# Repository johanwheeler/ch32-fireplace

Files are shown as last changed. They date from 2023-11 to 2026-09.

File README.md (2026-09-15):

# Merry Christmas!

And a happy new year! Here you will find some instructions for the christmas card, as well as some technical details. 

https://github.com/johanwheeler/ch32-fireplace/assets/45564940/a2e65534-c451-412c-9a83-9337bf3cca4e

[Longer demo here](https://photos.app.goo.gl/RaVmtgkoQ25G9iBE6), [Short Hackaday article](https://hackaday.com/2024/01/02/an-animated-led-fireplace-powered-by-the-ch32v003/)

# Instructions

If your card has white plastic in front of the screen, remove the front plate and peel the film, then connect to any USB-C power source. The stockings above the fire are actually touch buttons! Press firmly to interact.

Sound: Toggle sound on or off. 

Next: Go to next animation.

Present: Call for santa. Remember that santa will only deliver presents at night ;)

# Technical details

For fellow nerds.

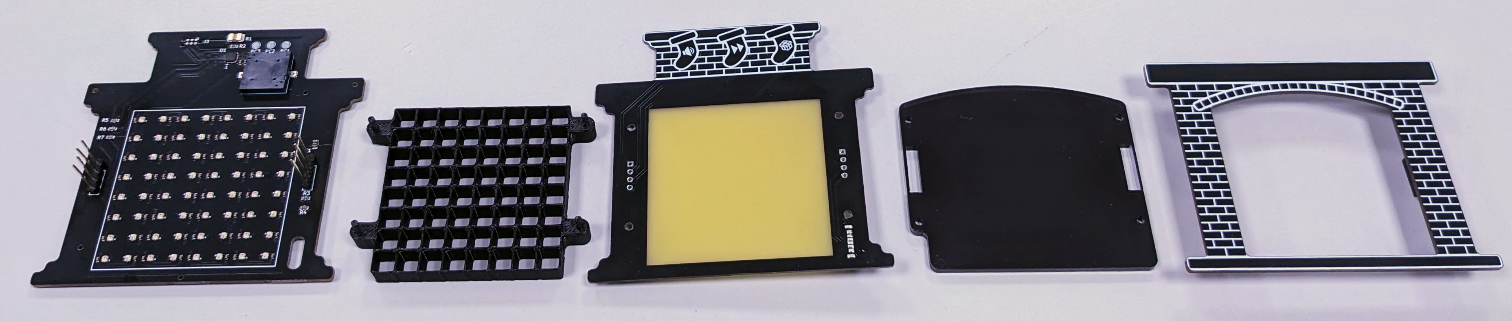
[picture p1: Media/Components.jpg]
Major components laid out


## Mechanical design

The initial shape was made in Fusion360, together with the grid and acrylic piece. The outlines were then imported into Inkscape, where the graphics were designed. To save ourselves a lot of work during the assembly process, we put an effort into minimizing part count as much as possible. We did this by combining multiple functions into one part, for example the middle PCB serves as decoration, diffuser for the LEDs, and also has buttons integrated. This way we managed to get all the looks and functionality with only 5 major mechanical components, saving us a lot of work when we eventually assembled all 50 of these.

## Electrical design

The main electrical components are:

 - CH32V003 RISC-V microcontroller
 - WS2812B (neopixel) LED matrix with 64 pixels
 - Buzzer for music and sound effects
 - Capacitive touch buttons
 - Photoresistor

These are distributed on 3 PCBs for a 3D effect, KiCAD was used to design the PCBs:

 - Back PCB has most of the components including MCU, Buzzer, LEDs, and programming headers.
 - Middle PCB has a USB-C port and capacitive buttons. Exposed FR-4 is used as a diffuser for the LEDs. 
 - Front PCB just looks nice.

## Assembly

The project is assembled in several steps that need to be followed in the correct order.

 - Components on back PCB.
 - Upload code (on back PCB).
 - Attach USB-C jack and grid on middle PCB.
 - Solder middle PCB to back PCB headers.
 - Attach acrylic on middle PCB.
 - Solder female headers on front PCB.
 - Attach front PCB.
 - Plug in and enjoy!

We got all of the back PCB smd components assembled by JLCPCB. We then set up a mini production line over the weekend and made 50 of these to give away to friends and family. The final cost came out to around 6$ per fireplace, manageable even with our student budgets. 

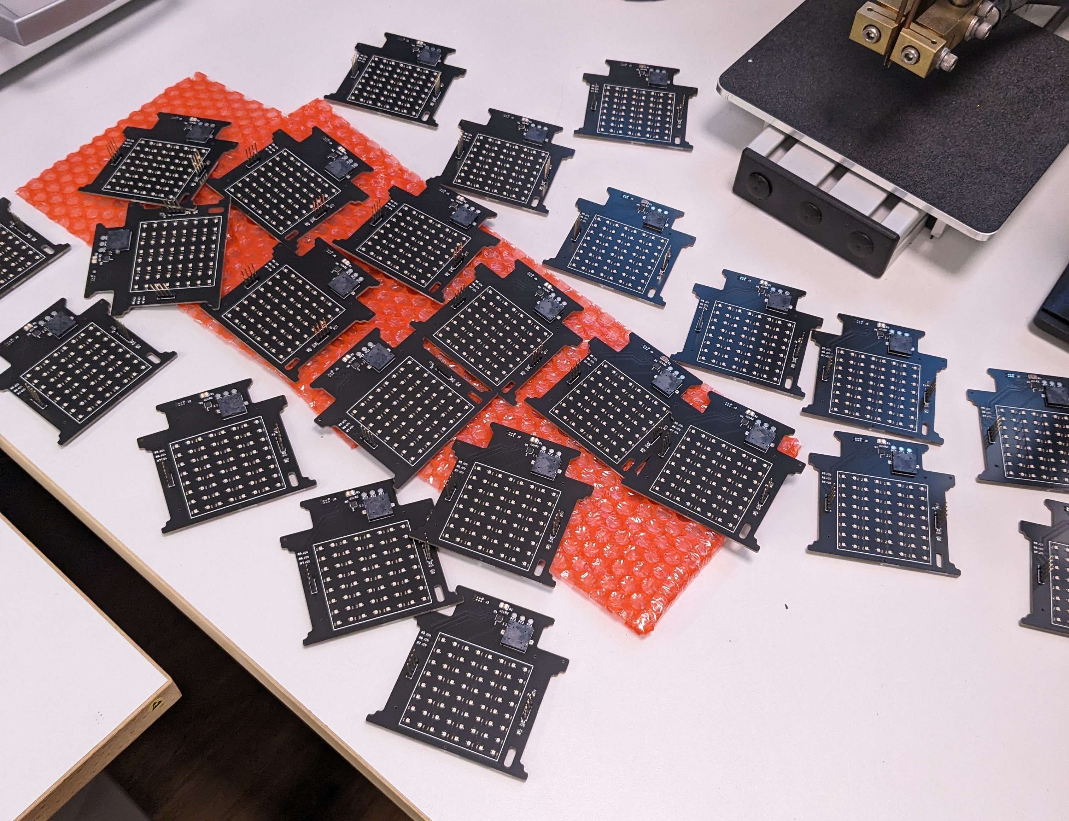
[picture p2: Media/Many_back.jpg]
Headers soldered to back


## Code

All code was written in plain C using the ch32v003fun dev environment and can be compiled using PlatformIO. The main code can be found in [src/main.c](SW/fireplace-PIO/src/main.c), and several peripheral drivers and functions can be found in the [lib](SW/fireplace-PIO/lib/) folder. The fire is procedurally generated, and the christmas tree has some math for the fading lights, otherwise the animations are stored frame by frame on the device. We really managed to squeeze a lot of functionality onto the 10 cent chip, with the code, animations and music filling up more than 90 percent of the 16k flash. 

# Contributions

This was a really fun project to do, and we learned a lot about small-scale production with limited budget and a tight deadline.

The people who made this:

 - Johan Wheeler (@johanwheeler): Electrical design, mechanical design, assembly.
 - Daniel Quach (@BasementCircuits): Project lead, electrical design, programming, animations, soldering.
 - Adam Anderson (@adaand00): Mechanical design, assembly, programming, animations. 

[See past years' cards!](https://github.com/Muoshy/christmas-cards)

Additional thanks to:

@CNLohr and contributors for the great resources in [ch32v003fun](https://github.com/cnlohr/ch32v003fun/tree/master).

CASE (Chalmers Autonomous Sytems and Electronics) for PCB shipping, tools, and workspace.

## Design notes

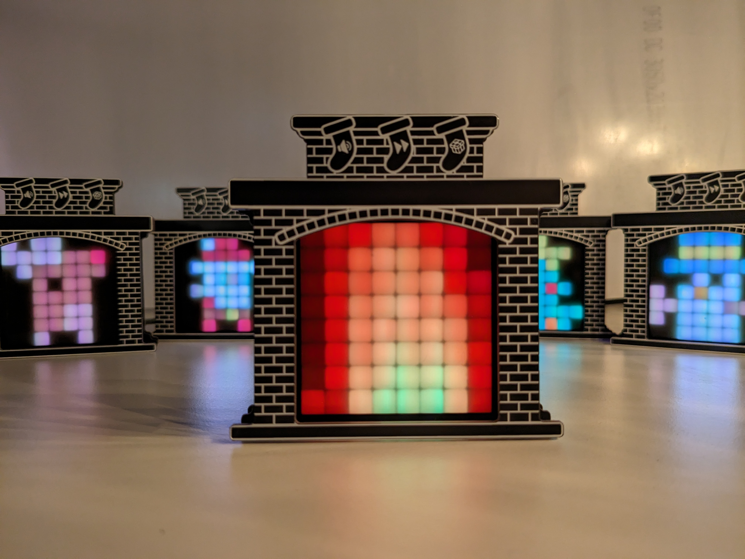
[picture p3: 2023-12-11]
Media/Display.jpg

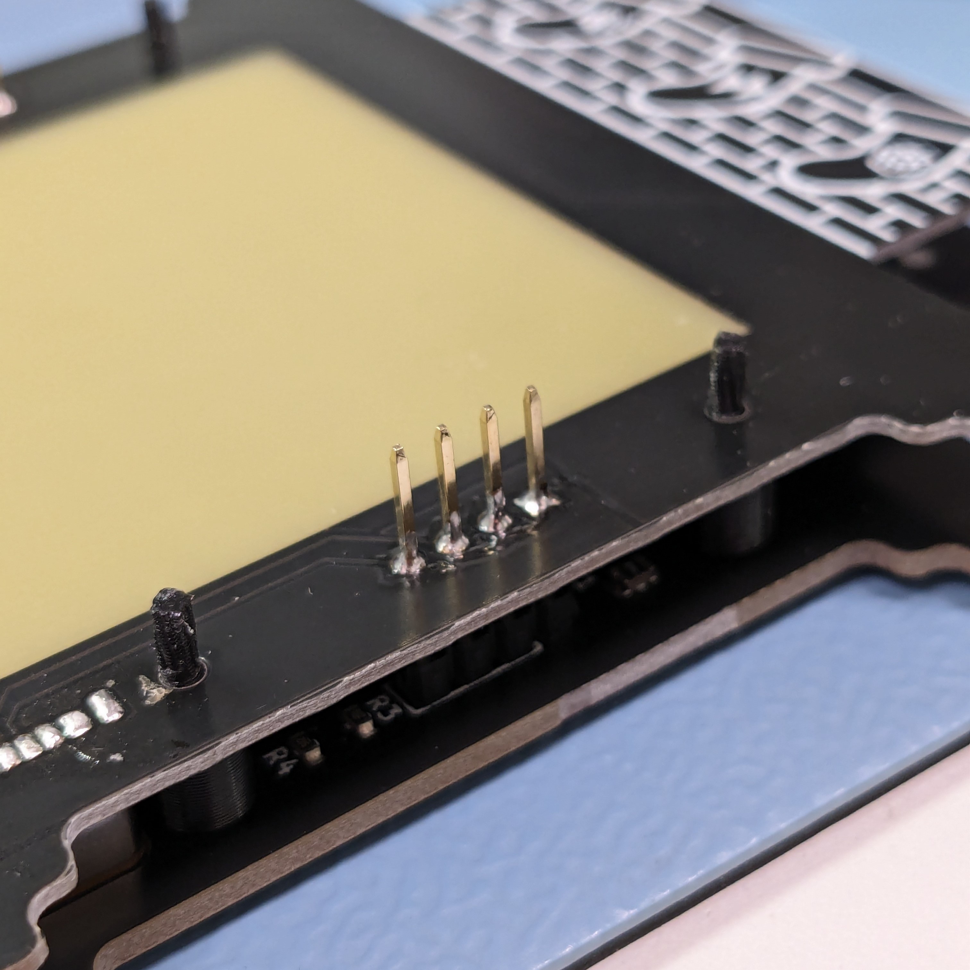
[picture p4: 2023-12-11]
Media/Mid_attached.jpg

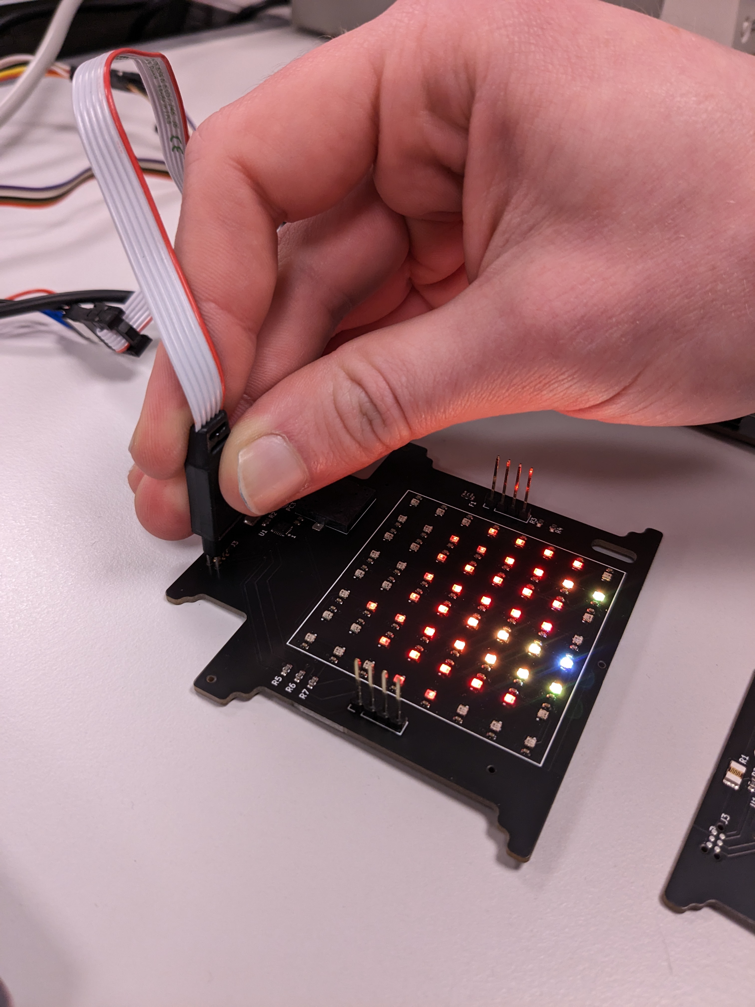
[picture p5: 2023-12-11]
Media/Programming.jpg

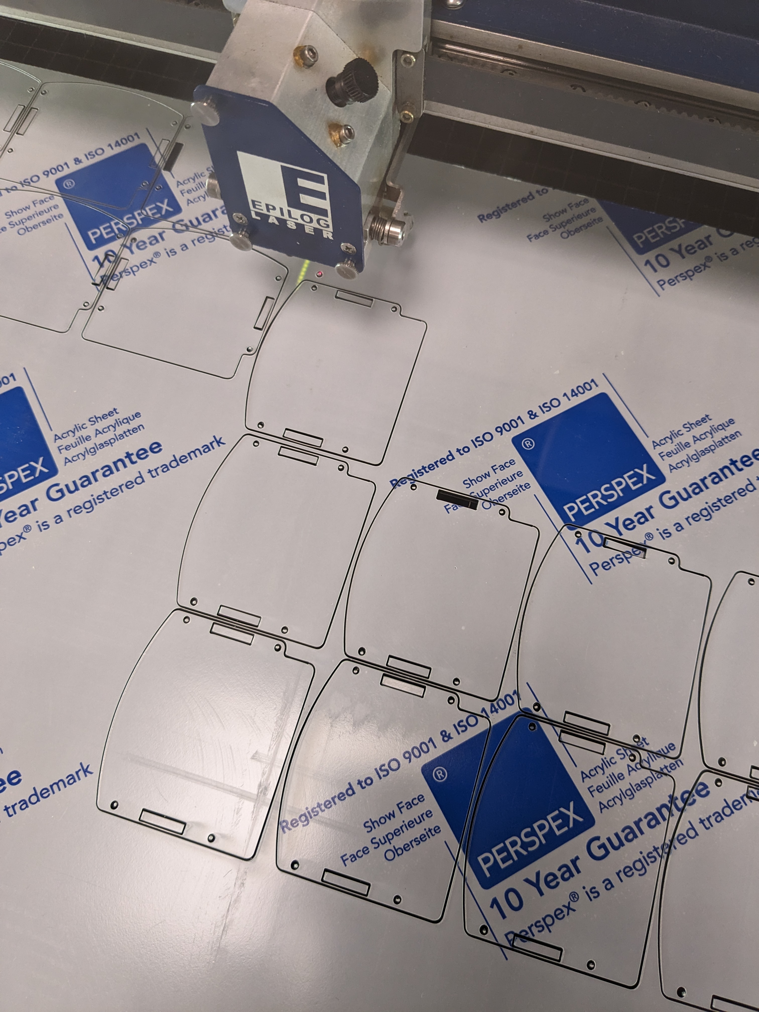
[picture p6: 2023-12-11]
Media/Laser.jpg

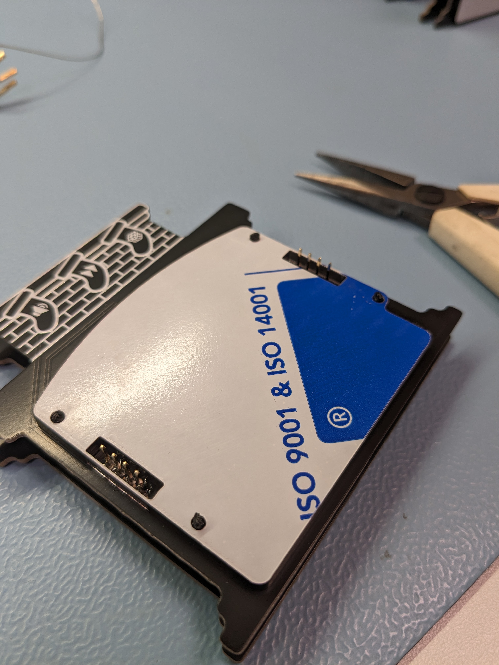
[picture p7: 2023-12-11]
Media/Acryllic.jpg

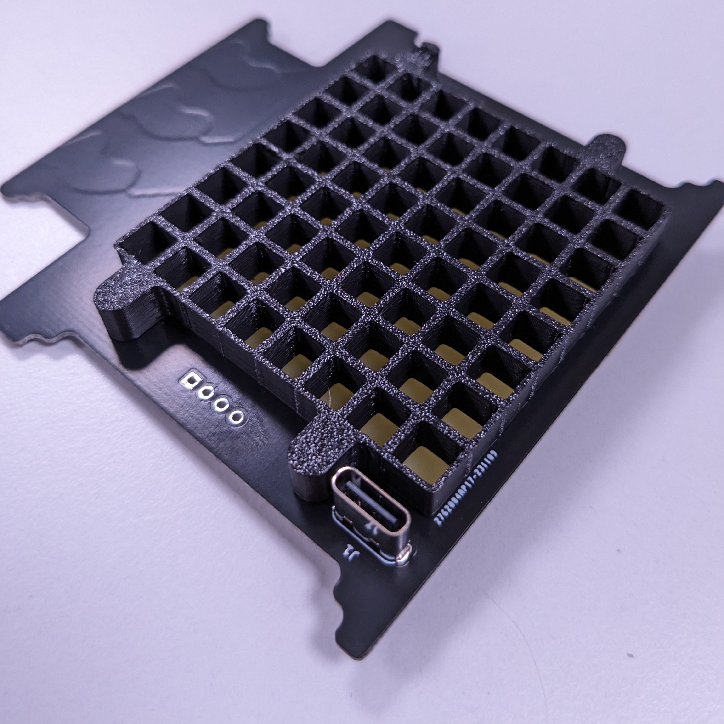
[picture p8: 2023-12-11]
Media/Mid_grid.jpg

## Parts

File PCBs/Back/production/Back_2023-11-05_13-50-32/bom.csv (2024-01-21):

Designator | Footprint | Quantity | Value | LCSC Part #
BZ1 | FUET-1325 | 1 | Buzzer | C391038
C1, C10, C11, C12, C13, C14, C15, C16, C17, C18, C19, C2, C20, C21, C22, C23, C24, C25, C26, C27, C28, C29, C3, C30, C31, C32, C33, C34, C35, C36, C37, C38, C39, C4, C40, C41, C42, C43, C44, C45, C46, C47, C48, C49, C5, C50, C51, C52, C53, C54, C55, C56, C57, C58, C59, C6, C60, C61, C62, C63, C64, C65, C66, C7, C8, C9 | 0402 | 66 | 100n | C1525
D1, D10, D11, D12, D13, D14, D15, D16, D17, D18, D19, D2, D20, D21, D22, D23, D24, D25, D26, D27, D28, D29, D3, D30, D31, D32, D33, D34, D35, D36, D37, D38, D39, D4, D40, D41, D42, D43, D44, D45, D46, D47, D48, D49, D5, D50, D51, D52, D53, D54, D55, D56, D57, D58, D59, D6, D60, D61, D62, D63, D64, D7, D8, D9 | XL-1615_WS2812B | 64 | RGB_1516 | C5349954
F1 | 0805 | 1 | 750mA | C269105
H1, H2, H3 | ToolingHole | 3 | Tooling
J1 | PinHeader_1x04_P2.54mm_Vertical | 1 | PWR_CONN
J4 | PinHeader_1x04_P2.54mm_Vertical | 1 | CAP_CONN
R1 | GT36528 | 1 | Photoresistor | C2904881
R2 | 0603 | 1 | 10k | C31850
R3, R4 | 0603 | 2 | 5.1k | C23186
R5, R6, R7 | 0603 | 3 | 560k | C23203
TP1 | TestPoint_Pad_D2.0mm | 1 | PC3
TP2 | TestPoint_Pad_D2.0mm | 1 | PC2
TP3 | TestPoint_Pad_D2.0mm | 1 | PC1
U1 | QFN-20-1EP_3x3mm_P0.4mm_EP1.65x1.65mm | 1 | CH32V003F4U6 | C5299908

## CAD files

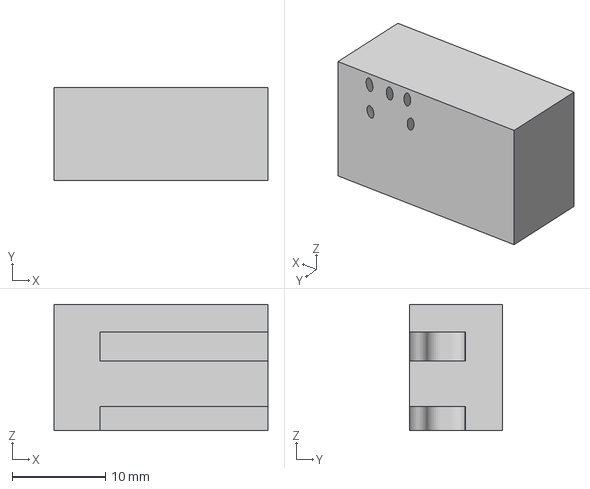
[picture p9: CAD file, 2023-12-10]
CAD/3D/pogo_block_0.1.3mf
23.0 x 10.0 x 13.6 mm

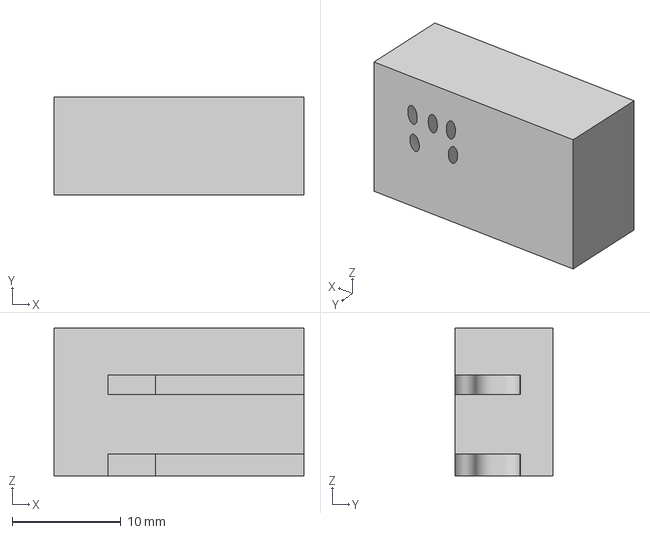
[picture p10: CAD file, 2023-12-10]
CAD/3D/pogo_block_v2/pogo_block_v2_mean_offset.3mf
23.0 x 9.00 x 13.6 mm

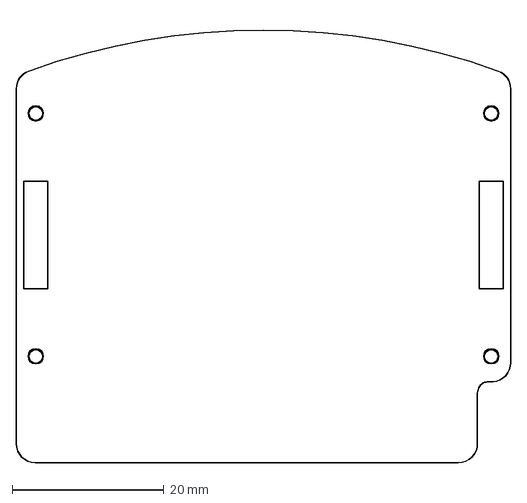
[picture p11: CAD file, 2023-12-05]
CAD/DXF/acrylic_v2.dxf
65.1 x 58.8 mm

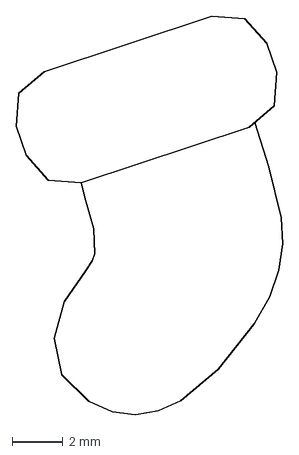
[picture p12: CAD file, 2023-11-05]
Graphics/sock_1mm.dxf
10.5 x 15.7 mm

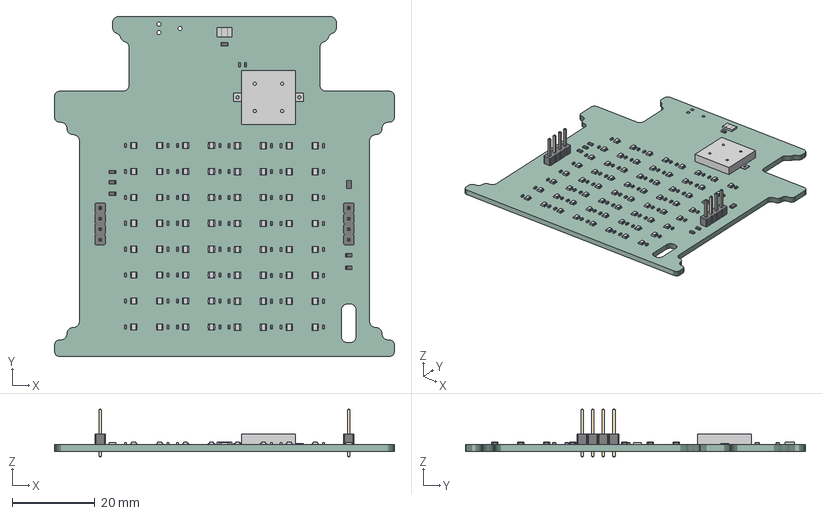
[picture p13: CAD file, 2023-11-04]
PCBs/Back/Back.step
82.0 x 82.0 x 11.5 mm
_autosave-Back PCB

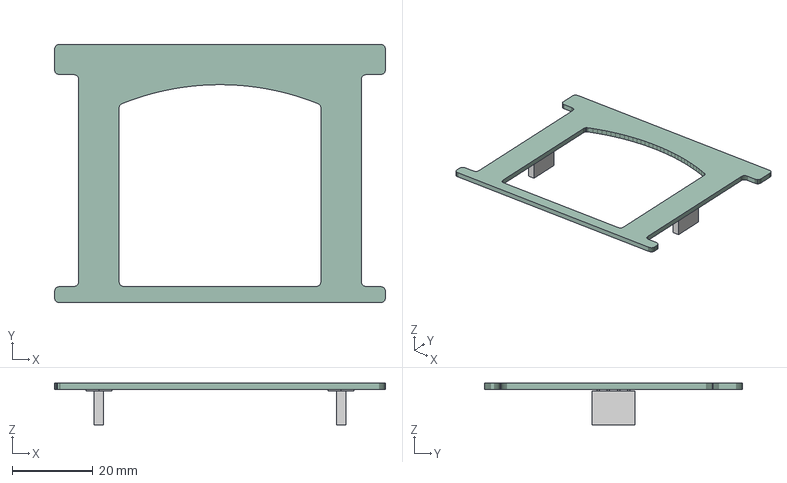
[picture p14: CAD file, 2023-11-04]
PCBs/Front/Front.step
82.0 x 64.0 x 10.4 mm
_autosave-Front PCB

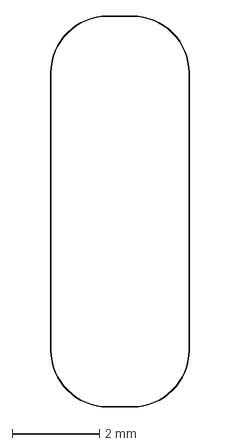
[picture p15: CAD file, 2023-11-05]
PCBs/Middle/usb-c-outline.dxf
3.16 x 8.94 mm

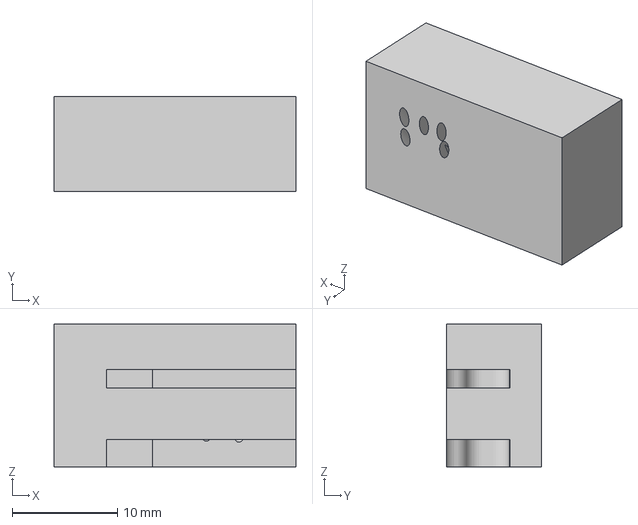
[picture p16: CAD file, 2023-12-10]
CAD/3D/pogo_block_v2/pogo_block_v2_back_front_offset.3mf
23.0 x 9.00 x 13.6 mm

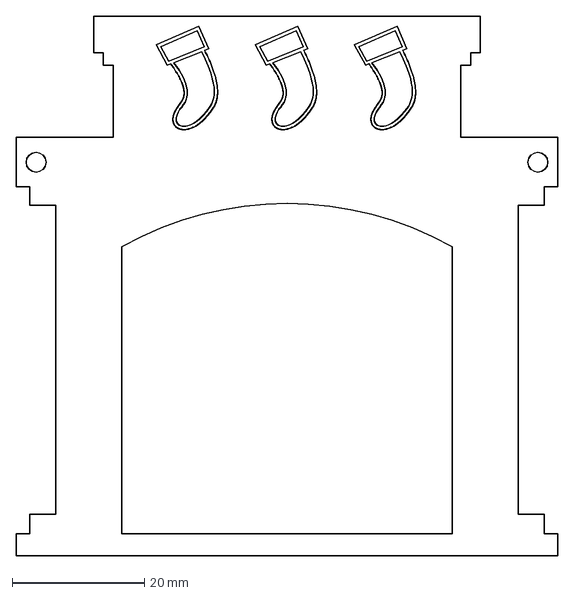
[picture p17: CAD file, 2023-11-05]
CAD/DXF/middle.dxf
82.0 x 81.7 mm

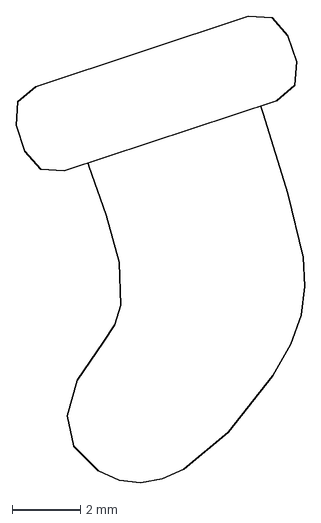
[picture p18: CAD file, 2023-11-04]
Graphics/sock.dxf
8.48 x 13.7 mm

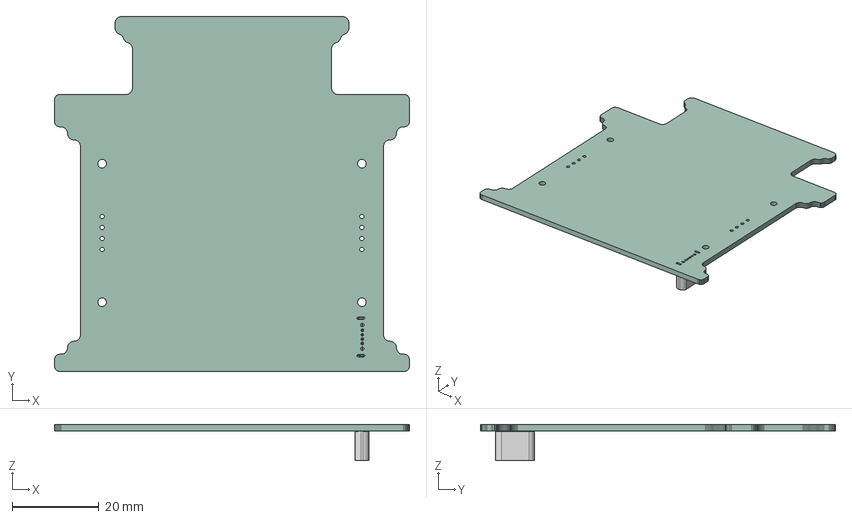
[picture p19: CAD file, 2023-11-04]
PCBs/Middle/Middle.step
82.0 x 82.0 x 8.43 mm
Middle PCB

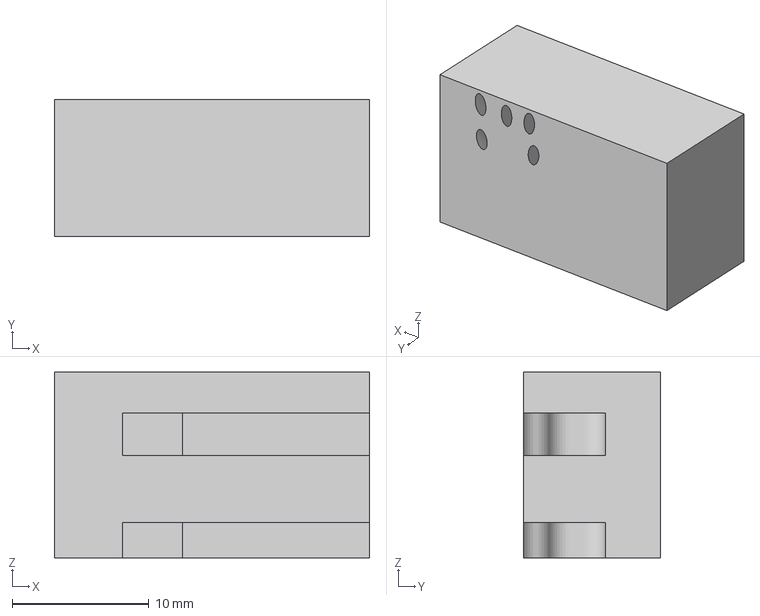
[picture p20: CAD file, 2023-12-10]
CAD/3D/pogo_block_0.2.3mf
23.0 x 10.0 x 13.6 mm

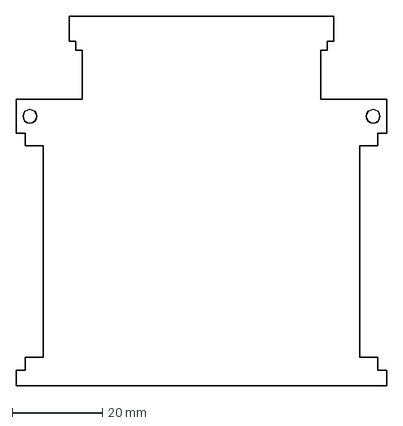
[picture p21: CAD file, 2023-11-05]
CAD/DXF/back.dxf
82.0 x 81.7 mm

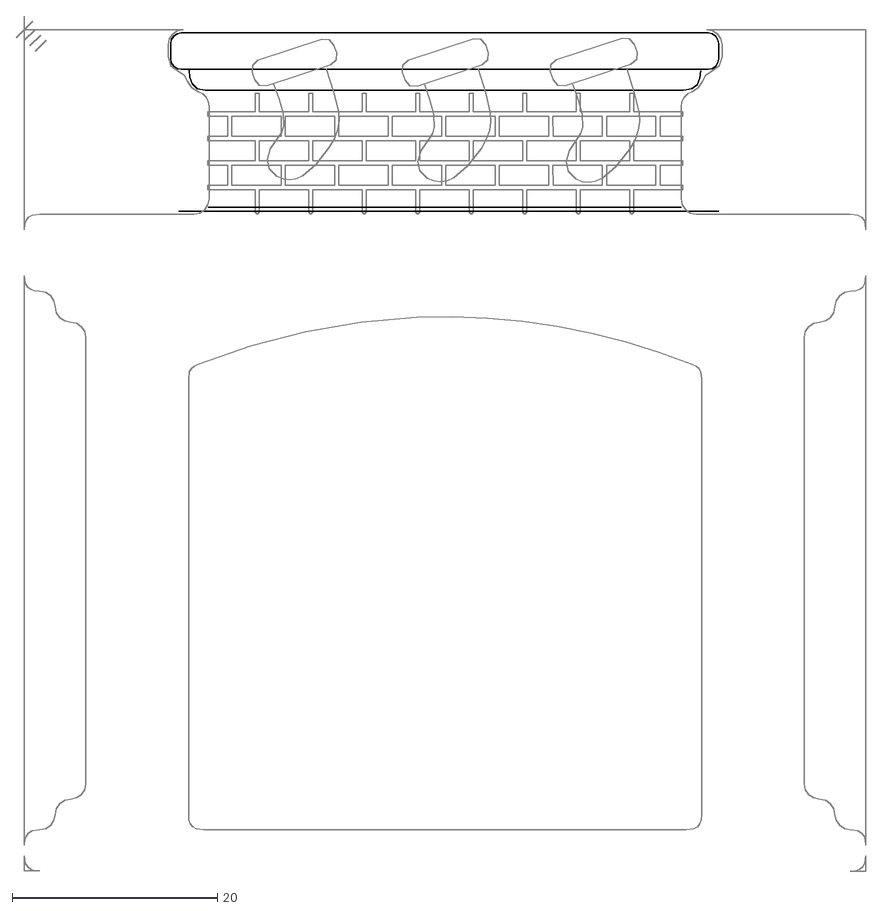
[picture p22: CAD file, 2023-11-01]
Graphics/Middle.dxf
82.8 x 83.3

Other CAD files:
CAD/3D/pogo_block_0.3mf
CAD/3D/pogo_block_printmf.3mf
CAD/DXF/usb-c-cutout.dxf
Graphics/Back.dxf
CAD/3D/1.5mm led grid.stl
CAD/3D/Grid_v3.0.3mf
CAD/3D/Grid_v3.0_diffuse_print.3mf
CAD/3D/Grid_v3.0_print.3mf
CAD/3D/Grid_v3.1.3mf
CAD/3D/Grid_v3.1_6.5mm_high.3mf
CAD/3D/Grid_v3.1_print3mf.3mf
CAD/3D/blablab.3mf
CAD/3D/buzzer_C391038.step
CAD/3D/female_pin_header.step
CAD/3D/footprint_test v2.step
CAD/3D/led_C191KRKT.step
CAD/3D/photo_GT36528.step
CAD/3D/pinHeaderJig.3mf
CAD/3D/pinHeaderJig_v2.3mf
CAD/3D/pinHeaderJig_v3.3mf
CAD/3D/pinHeaderJig_v4.3mf
CAD/3D/pinHeaderJig_v4_print.3mf
CAD/3D/pogo_block_0.3.3mf
CAD/3D/pogo_block_0.4.3mf
CAD/3D/pogo_block_print_V2.3mf
CAD/DXF/front.dxf
Graphics/Front.dxf

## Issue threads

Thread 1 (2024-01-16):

Recreation

AaHug, 2024-01-16:
I'm pretty amature at this, and have a much more knowledge friend helping me.  He was trying to upload the PCB files to jlcpcb.  It wasn't generating a needed parts list.  I've been told we are looking for a Bill of Materials and a Placement file.  Any help would be appreciated.

Muoshy, 2024-01-21:
Good catch! Seems like the BOM and placements files (.csv) were excluded by our gitignore. It should be fixed now. You can find them in PCBs/Back/Production. Otherwise, you can generate the BOM and placement files with the fabrication toolkit plugin in KiCad. The KiCad files should contain the JLCPCB part numbers.

Let me know if you need additional help or if I can close the issue.

AaHug, 2024-01-21:
It's fixed now.  Thank you so much for your help.

Aaron Hugenberg

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

Closed 2024-01-22.

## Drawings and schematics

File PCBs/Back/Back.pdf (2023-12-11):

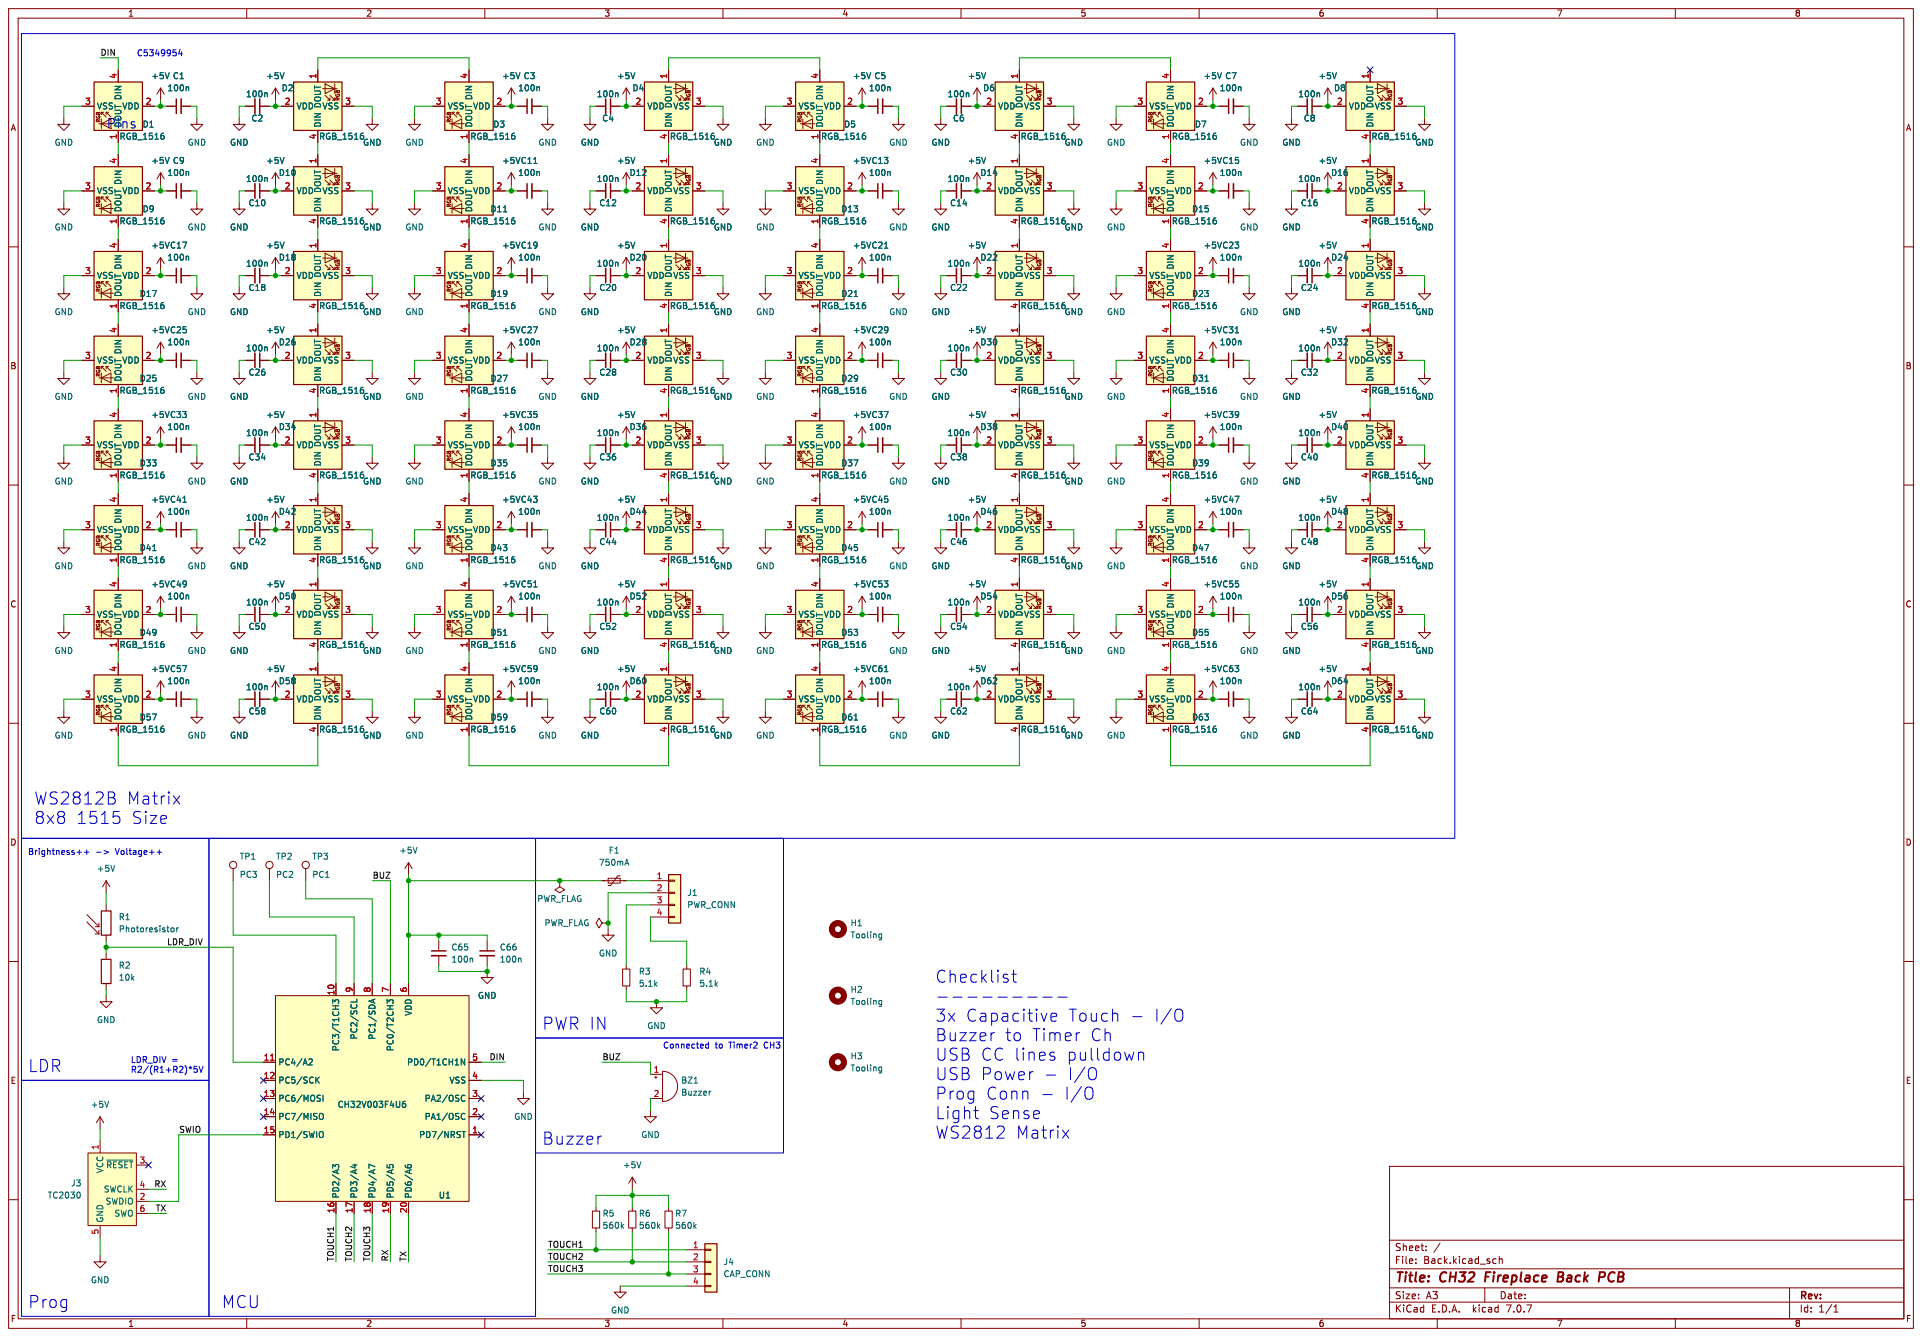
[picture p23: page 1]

4 D22 RGB_1516 GND GND RGB DOUT

4 D11 RGB_1516 GND GND GND GND GND GND GND

100n GND GND GND GND

4 D46 RGB_1516 GND GND GND GND GND GND
100n +5V GND

4 GND GND GND GND GND GND GND GND

4 D60 RGB_1516 GND GND GND GND RGB DOUT

4 D32 RGB_1516 GND GND RGB DOUT

4 D62 RGB_1516 GND GND GND GND GND

4 U1 CH32V003F4U6 PD7/NRST 1 PC3/T1CH3 10 PC4/A2 11 PC5/SCK 12 PC6/MOSI 13 PC7/MISO 14 PD1/SWIO 15 PD2/A3 16 PD3/A4 17 PD4/A7 18 PD5/A5 19 PA1/OSC 2 PD6/A6 20 PA2/OSC 3 VSS 4 PD0/T1CH1N 5 VDD

Connected to Timer2 CH3 PWR IN

Buzzer to Timer Ch
USB CC lines pulldown
USB Power - I/O
Prog Conn - I/O
Light Sense
WS2812 Matrix

1 SWDIO 2 ~{RESET}3 SWCLK 4 GND

Id: 1/1 Title: CH32 Fireplace Back PCB

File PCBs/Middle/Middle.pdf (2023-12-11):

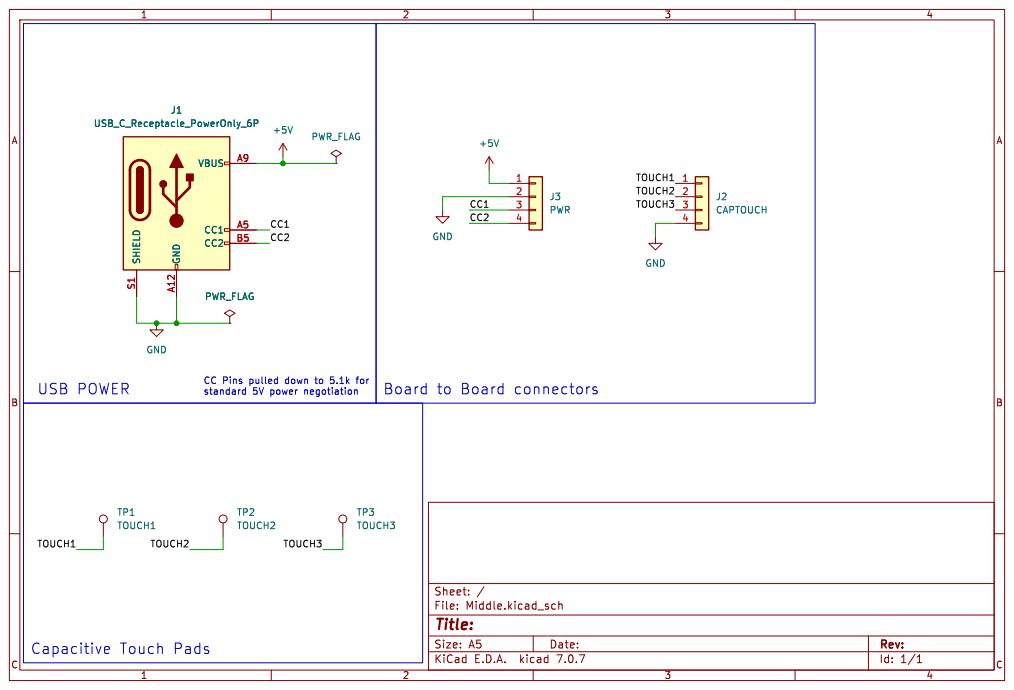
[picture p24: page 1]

J1 USB_C_Receptacle_PowerOnly_6P | +5V

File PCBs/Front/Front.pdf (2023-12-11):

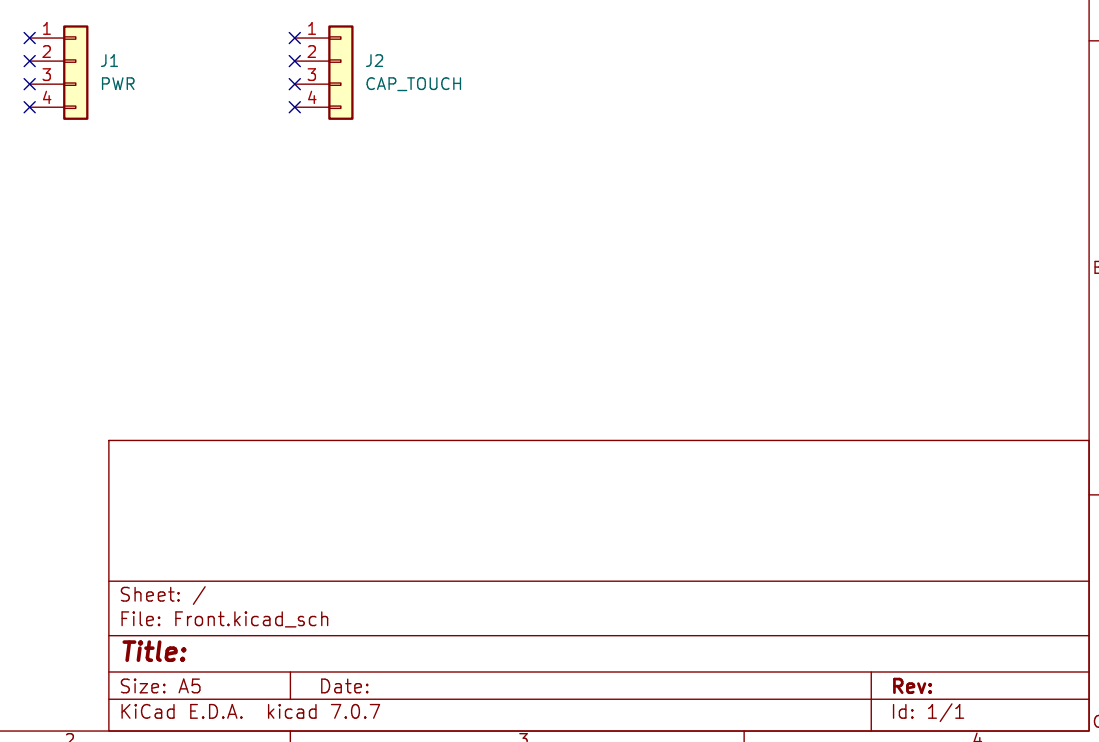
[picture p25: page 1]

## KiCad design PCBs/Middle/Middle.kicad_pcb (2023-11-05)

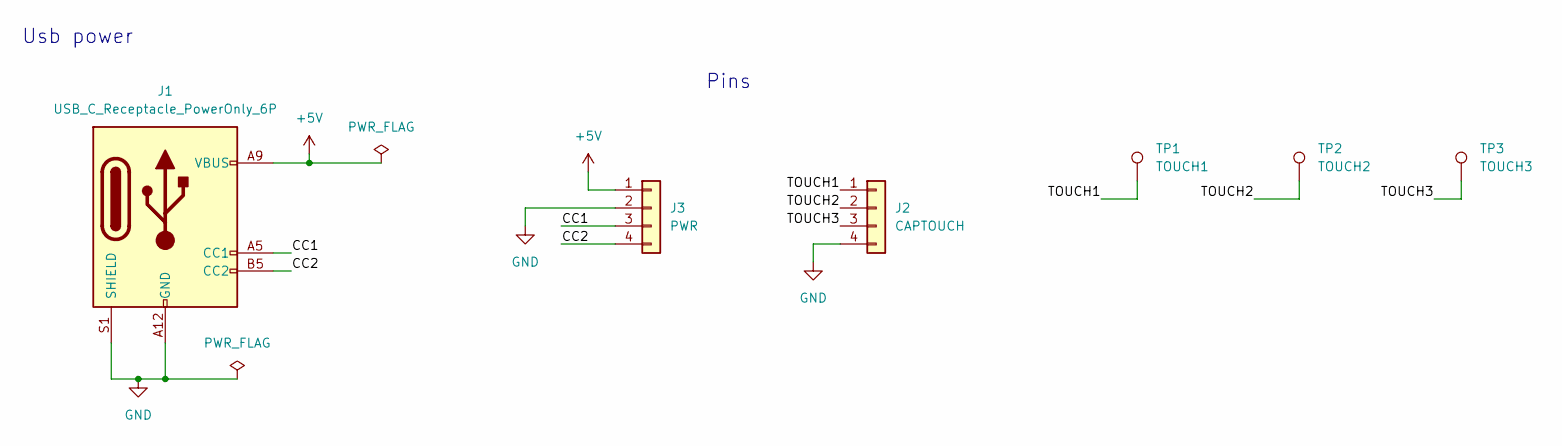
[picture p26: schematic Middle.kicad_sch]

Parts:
J1: USB_C_Receptacle_PowerOnly_6P; TYPE-C-31-D-08
J2: CAPTOUCH; PinHeader_1x04_P2.54mm_Vertical
J3: PWR; PinHeader_1x04_P2.54mm_Vertical
TP1: TOUCH1; cap_sock
TP2: TOUCH2; cap_sock
TP3: TOUCH3; cap_sock

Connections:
+5V: J1.A9 (VBUS), J1.B9 (VBUS), J3.1
/CC1: J1.A5 (CC1), J3.3
/CC2: J1.B5 (CC2), J3.4
/TOUCH1: J2.1, TP1.1
/TOUCH2: J2.2, TP2.1
/TOUCH3: J2.3, TP3.1
GND: J1.A12 (GND), J1.B12 (GND), J1.S1 (SHIELD), J2.4, J3.2

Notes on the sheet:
Usb power
Pins

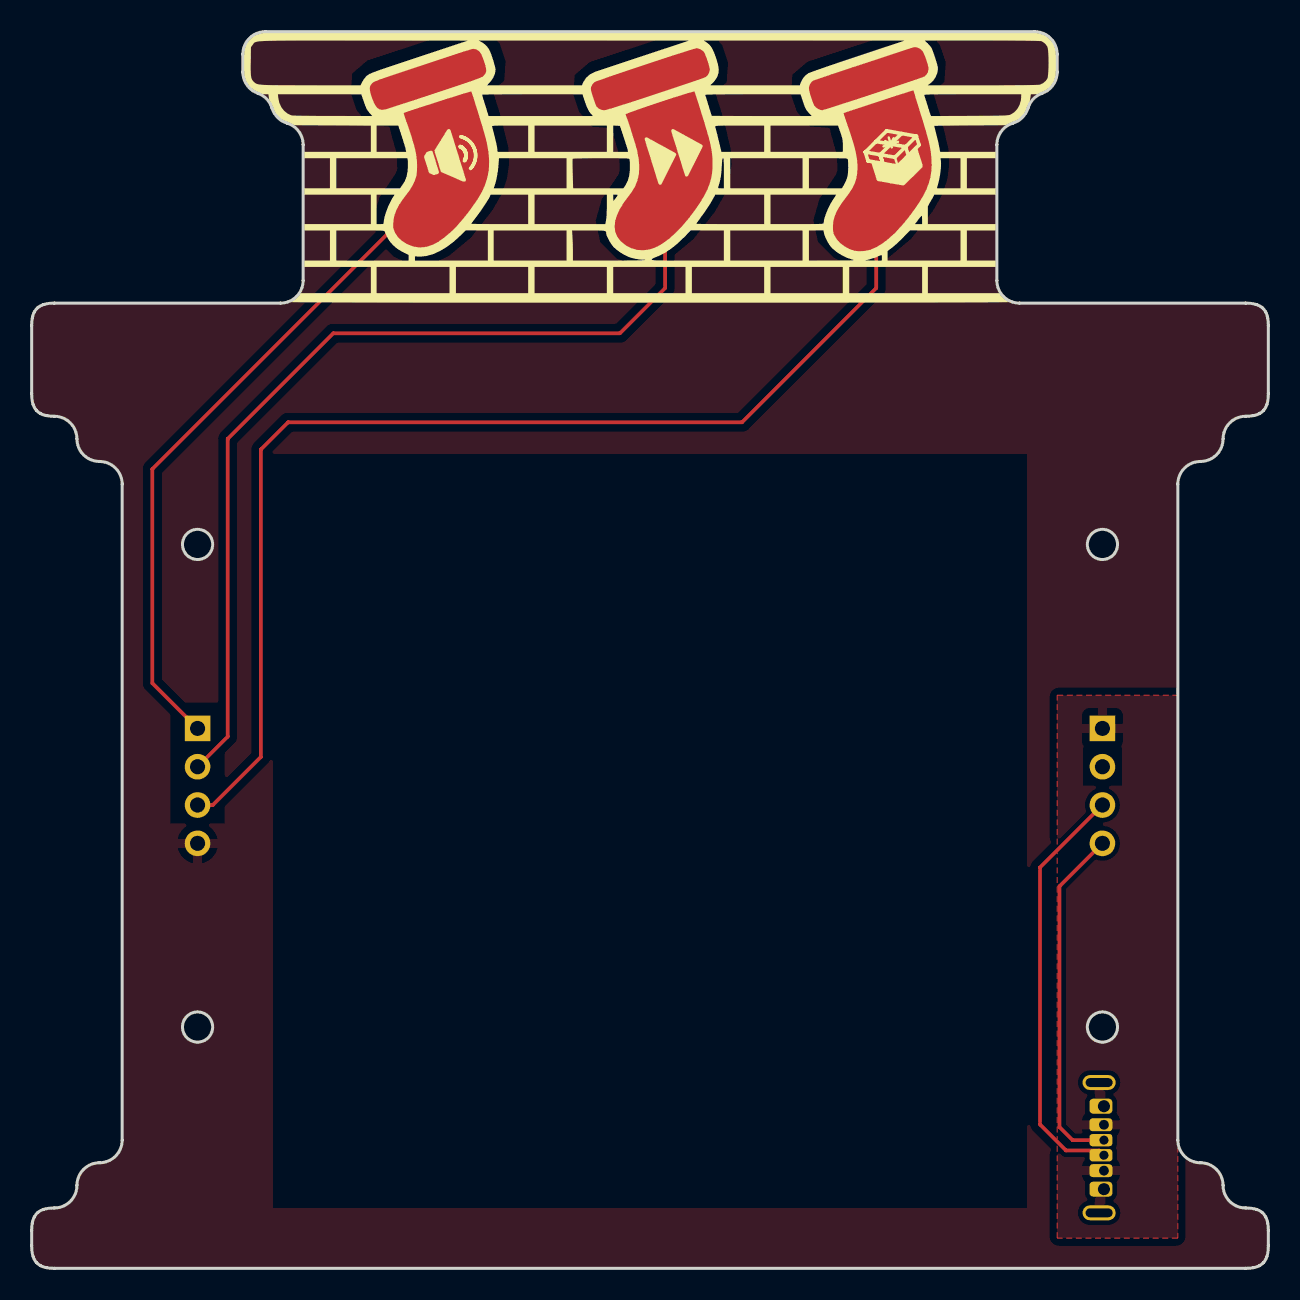
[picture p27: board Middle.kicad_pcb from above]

Board: 2 copper layers, 82.0 x 82.0 mm, 6 parts (1 on the bottom side), 7 nets.

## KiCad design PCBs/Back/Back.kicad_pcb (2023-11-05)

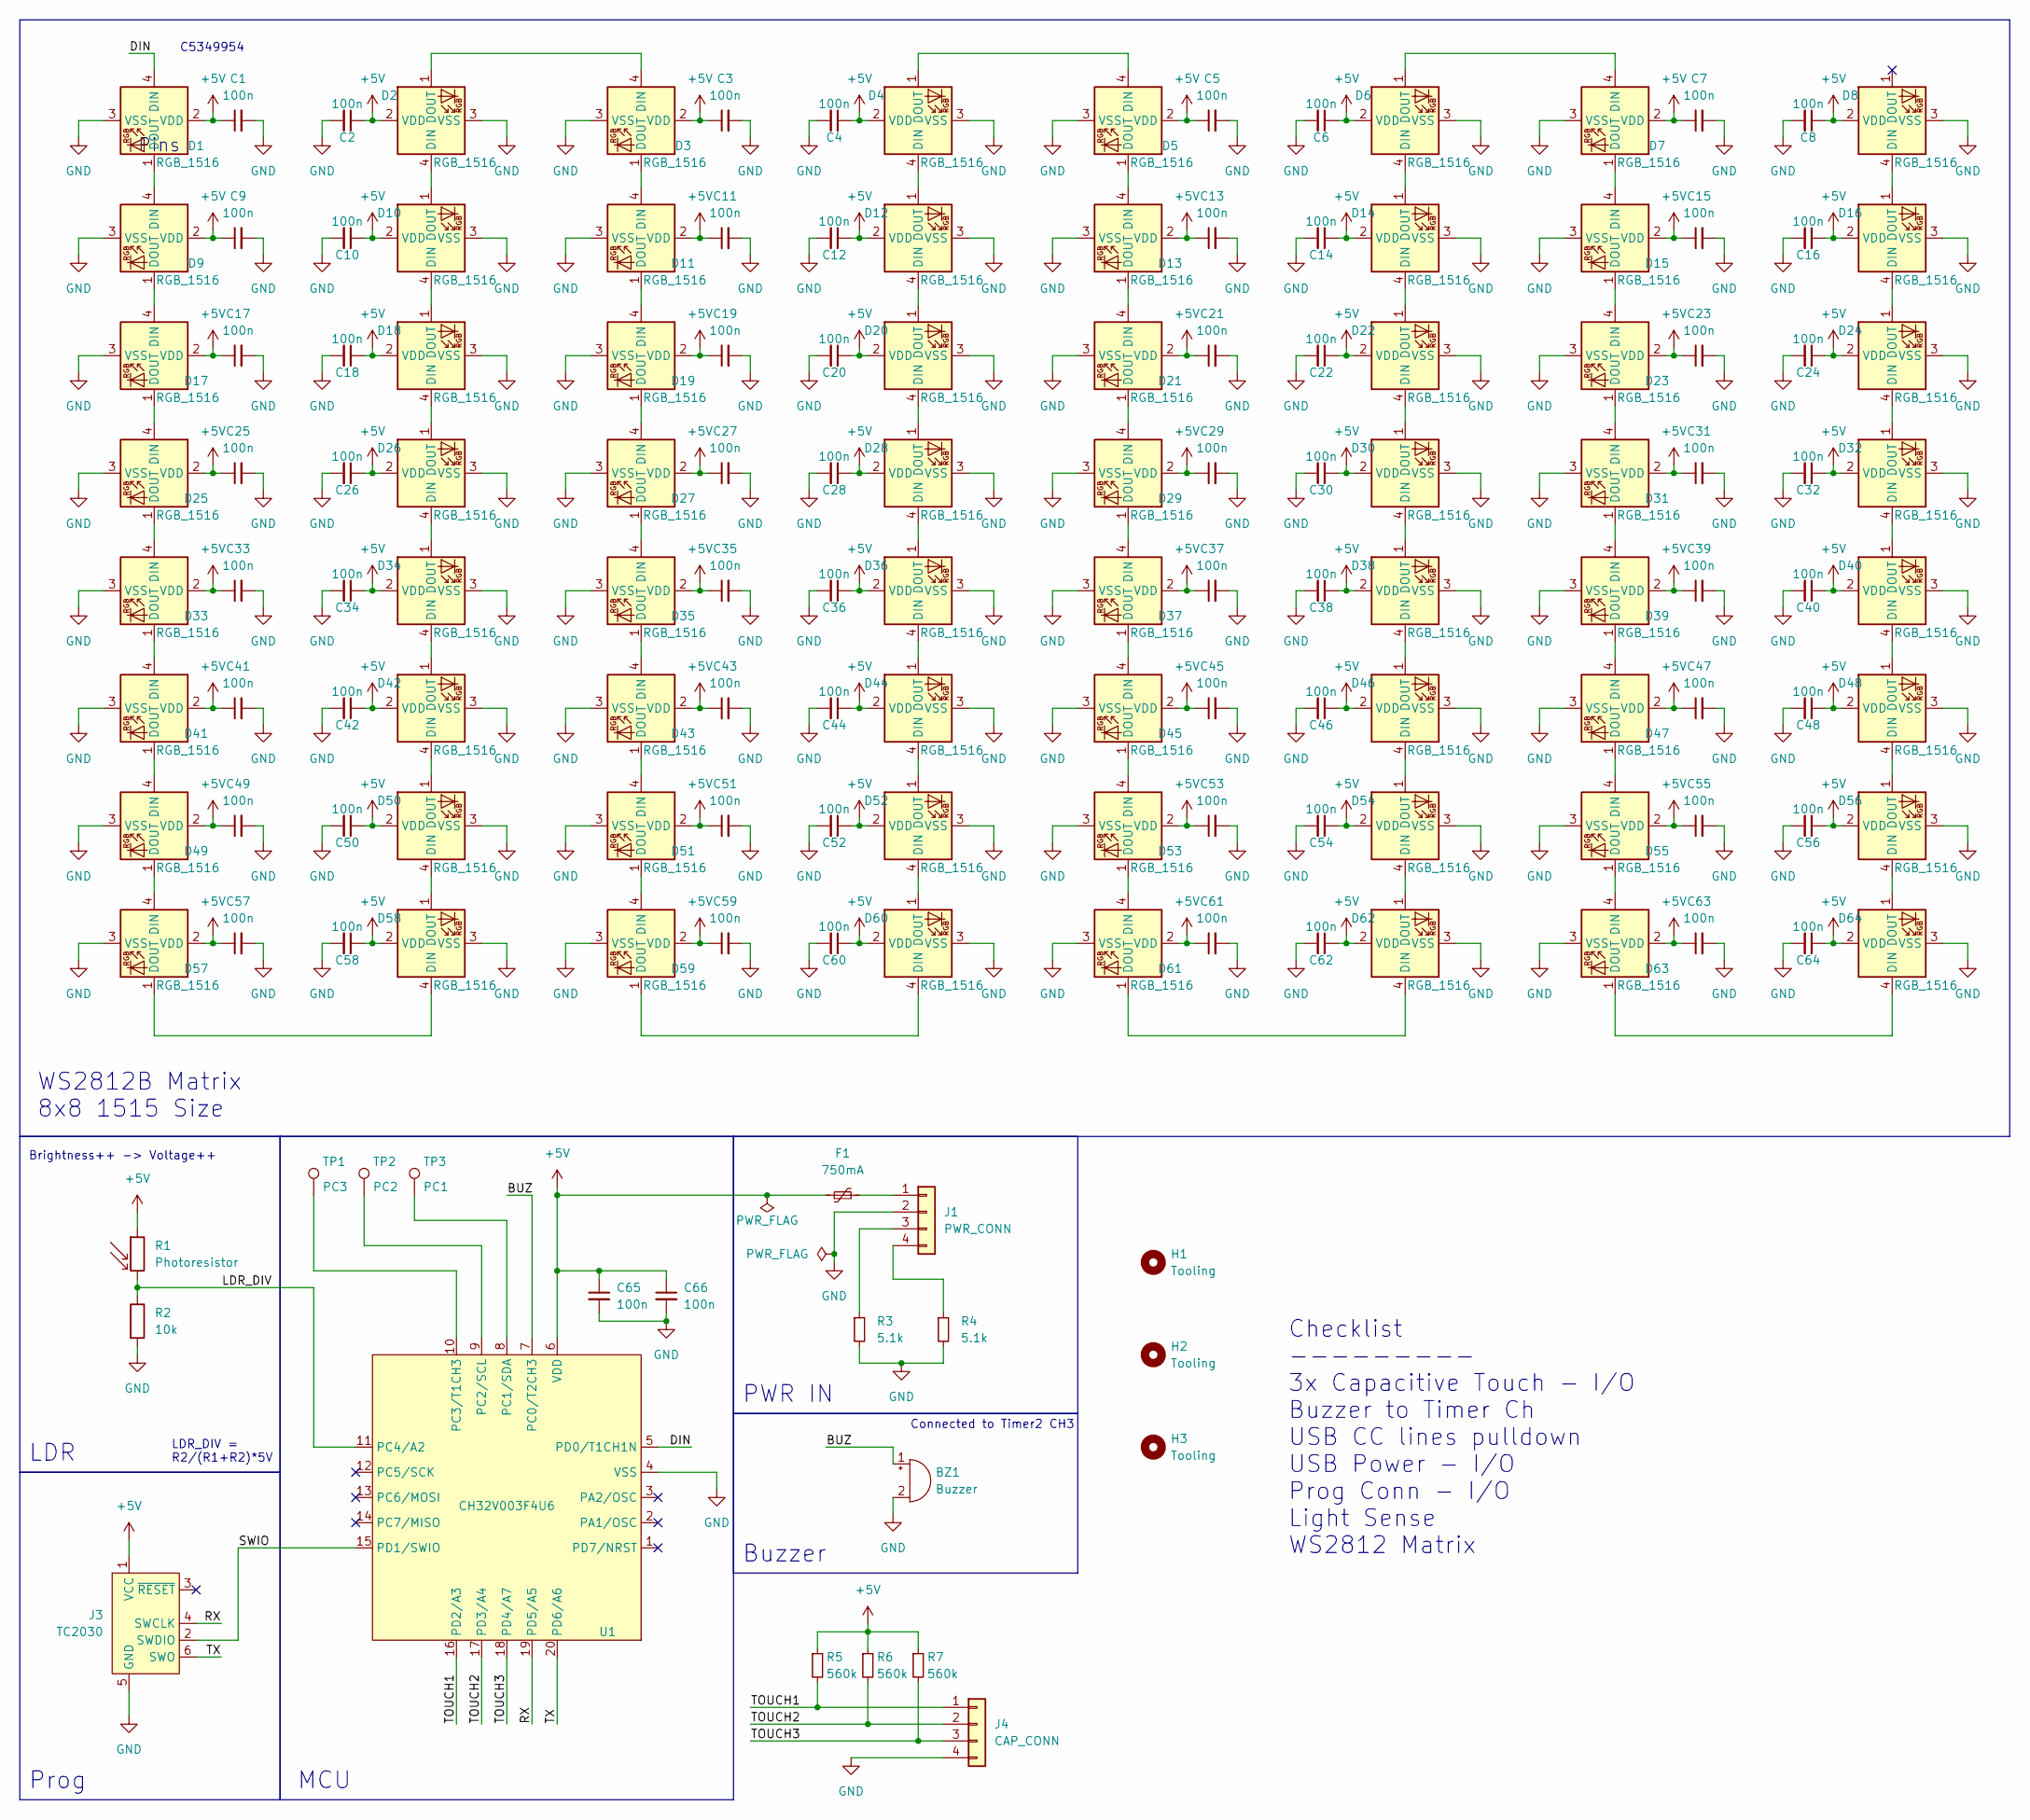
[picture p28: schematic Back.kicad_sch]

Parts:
BZ1: Buzzer; FUET-1325; MPN C391038; LCSC C391038
C1, C2, C3, C4, C5, C6, C7, C8, C9, C10, C11, C12, C13, C14, C15, C16, C17, C18, C19, C20, C21, C22, C23, C24, C25, C26, C27, C28, C29, C30, C31, C32, C33, C34, C35, C36, C37, C38, C39, C40, C41, C42, C43, C44, C45, C46, C47, C48, C49, C50, C51, C52, C53, C54, C55, C56, C57, C58, C59, C60, C61, C62, C63, C64, C65, C66: 100n; C_0402_1005Metric; MPN C1525; LCSC C1525
D1, D2, D3, D4, D5, D6, D7, D8, D9, D10, D11, D12, D13, D14, D15, D16, D17, D18, D19, D20, D21, D22, D23, D24, D25, D26, D27, D28, D29, D30, D31, D32, D33, D34, D35, D36, D37, D38, D39, D40, D41, D42, D43, D44, D45, D46, D47, D48, D49, D50, D51, D52, D53, D54, D55, D56, D57, D58, D59, D60, D61, D62, D63, D64: RGB_1516; XL-1615_WS2812B; MPN C5349954; LCSC C5349954
F1: 750mA; R_0805_2012Metric; MPN C269105; LCSC C269105
H1, H2, H3: Tooling; ToolingHole
J1: PWR_CONN; PinHeader_1x04_P2.54mm_Vertical
J3: TC2030; Tag-Connect_TC2030-IDC-NL_2x03_P1.27mm_Vertical
J4: CAP_CONN; PinHeader_1x04_P2.54mm_Vertical
R1: Photoresistor; GT36528; MPN C2904881; LCSC C2904881
R2: 10k; R_0603_1608Metric; MPN C25804; LCSC C25804
R3, R4: 5.1k; R_0603_1608Metric; MPN C23186; LCSC C23186
R5, R6, R7: 560k; R_0603_1608Metric; MPN C23203; LCSC C23203
TP1: PC3; TestPoint_Pad_D2.0mm
TP2: PC2; TestPoint_Pad_D2.0mm
TP3: PC1; TestPoint_Pad_D2.0mm
U1: CH32V003F4U6; QFN-20-1EP_3x3mm_P0.4mm_EP1.65x1.65mm; MPN C5299908; LCSC C5299908

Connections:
+5V: C1.1, C2.1, C3.1, C4.1, C5.1, C6.1, C7.1, C8.1, C9.1, C10.1, C11.1, C12.1, C13.1, C14.1, C15.1, C16.1, C17.1, C18.1, C19.1, C20.1, C21.1, C22.1, C23.1, C24.1, C25.1, C26.1, C27.1, C28.1, C29.1, C30.1, C31.1, C32.1, C33.1, C34.1, C35.1, C36.1, C37.1, C38.1, C39.1, C40.1, C41.1, C42.1, C43.1, C44.1, C45.1, C46.1, C47.1, C48.1, C49.1, C50.1, C51.1, C52.1, C53.1, C54.1, C55.1, C56.1, C57.1, C58.1, C59.1, C60.1, C61.1, C62.1, C63.1, C64.1, C65.1, C66.1, D1.2 (VDD), D2.2 (VDD), D3.2 (VDD), D4.2 (VDD), D5.2 (VDD), D6.2 (VDD), D7.2 (VDD), D8.2 (VDD), D9.2 (VDD), D10.2 (VDD), D11.2 (VDD), D12.2 (VDD), D13.2 (VDD), D14.2 (VDD), D15.2 (VDD), D16.2 (VDD), D17.2 (VDD), D18.2 (VDD), D19.2 (VDD), D20.2 (VDD), D21.2 (VDD), D22.2 (VDD), D23.2 (VDD), D24.2 (VDD), D25.2 (VDD), D26.2 (VDD), D27.2 (VDD), D28.2 (VDD), D29.2 (VDD), D30.2 (VDD), D31.2 (VDD), D32.2 (VDD), D33.2 (VDD), D34.2 (VDD), D35.2 (VDD), D36.2 (VDD), D37.2 (VDD), D38.2 (VDD), D39.2 (VDD), D40.2 (VDD), D41.2 (VDD), D42.2 (VDD), D43.2 (VDD), D44.2 (VDD), D45.2 (VDD), D46.2 (VDD), D47.2 (VDD), D48.2 (VDD), D49.2 (VDD), D50.2 (VDD), D51.2 (VDD), D52.2 (VDD), D53.2 (VDD), D54.2 (VDD), D55.2 (VDD), D56.2 (VDD), D57.2 (VDD), D58.2 (VDD), D59.2 (VDD), D60.2 (VDD), D61.2 (VDD), D62.2 (VDD), D63.2 (VDD), D64.2 (VDD), F1.1, J3.1 (VCC), R1.1, R5.1, R6.1, R7.1, U1.6 (VDD)
/BUZ: BZ1.1 (-), U1.7 (PC0/T2CH3)
/DIN: D1.4 (DIN), U1.5 (PD0/T1CH1N)
/LDR_DIV: R1.2, R2.1, U1.11 (PC4/A2)
/RX: J3.4 (SWCLK), U1.19 (PD5/A5)
/SWIO: J3.2 (SWDIO), U1.15 (PD1/SWIO)
/TOUCH1: J4.1, R5.2, U1.16 (PD2/A3)
/TOUCH2: J4.2, R6.2, U1.17 (PD3/A4)
/TOUCH3: J4.3, R7.2, U1.18 (PD4/A7)
/TX: J3.6 (SWO), U1.20 (PD6/A6)
GND: BZ1.2 (+), C1.2, C2.2, C3.2, C4.2, C5.2, C6.2, C7.2, C8.2, C9.2, C10.2, C11.2, C12.2, C13.2, C14.2, C15.2, C16.2, C17.2, C18.2, C19.2, C20.2, C21.2, C22.2, C23.2, C24.2, C25.2, C26.2, C27.2, C28.2, C29.2, C30.2, C31.2, C32.2, C33.2, C34.2, C35.2, C36.2, C37.2, C38.2, C39.2, C40.2, C41.2, C42.2, C43.2, C44.2, C45.2, C46.2, C47.2, C48.2, C49.2, C50.2, C51.2, C52.2, C53.2, C54.2, C55.2, C56.2, C57.2, C58.2, C59.2, C60.2, C61.2, C62.2, C63.2, C64.2, C65.2, C66.2, D1.3 (VSS), D2.3 (VSS), D3.3 (VSS), D4.3 (VSS), D5.3 (VSS), D6.3 (VSS), D7.3 (VSS), D8.3 (VSS), D9.3 (VSS), D10.3 (VSS), D11.3 (VSS), D12.3 (VSS), D13.3 (VSS), D14.3 (VSS), D15.3 (VSS), D16.3 (VSS), D17.3 (VSS), D18.3 (VSS), D19.3 (VSS), D20.3 (VSS), D21.3 (VSS), D22.3 (VSS), D23.3 (VSS), D24.3 (VSS), D25.3 (VSS), D26.3 (VSS), D27.3 (VSS), D28.3 (VSS), D29.3 (VSS), D30.3 (VSS), D31.3 (VSS), D32.3 (VSS), D33.3 (VSS), D34.3 (VSS), D35.3 (VSS), D36.3 (VSS), D37.3 (VSS), D38.3 (VSS), D39.3 (VSS), D40.3 (VSS), D41.3 (VSS), D42.3 (VSS), D43.3 (VSS), D44.3 (VSS), D45.3 (VSS), D46.3 (VSS), D47.3 (VSS), D48.3 (VSS), D49.3 (VSS), D50.3 (VSS), D51.3 (VSS), D52.3 (VSS), D53.3 (VSS), D54.3 (VSS), D55.3 (VSS), D56.3 (VSS), D57.3 (VSS), D58.3 (VSS), D59.3 (VSS), D60.3 (VSS), D61.3 (VSS), D62.3 (VSS), D63.3 (VSS), D64.3 (VSS), J1.2, J3.5 (GND), J4.4, R2.2, R3.2, R4.2, U1.4 (VSS), U1.21 (VSS)
unnamed: D1.1 (DOUT), D9.4 (DIN)
unnamed: D2.1 (DOUT), D3.4 (DIN)
unnamed: D4.1 (DOUT), D5.4 (DIN)
unnamed: D6.1 (DOUT), D7.4 (DIN)
unnamed: D10.4 (DIN), D18.1 (DOUT)
unnamed: D2.4 (DIN), D10.1 (DOUT)
unnamed: D3.1 (DOUT), D11.4 (DIN)
unnamed: D11.1 (DOUT), D19.4 (DIN)
unnamed: D12.4 (DIN), D20.1 (DOUT)
unnamed: D4.4 (DIN), D12.1 (DOUT)
unnamed: D5.1 (DOUT), D13.4 (DIN)
unnamed: D13.1 (DOUT), D21.4 (DIN)
unnamed: D14.4 (DIN), D22.1 (DOUT)
unnamed: D6.4 (DIN), D14.1 (DOUT)
unnamed: D7.1 (DOUT), D15.4 (DIN)
unnamed: D15.1 (DOUT), D23.4 (DIN)
unnamed: D16.4 (DIN), D24.1 (DOUT)
unnamed: D8.4 (DIN), D16.1 (DOUT)
unnamed: D9.1 (DOUT), D17.4 (DIN)
unnamed: D17.1 (DOUT), D25.4 (DIN)
unnamed: D18.4 (DIN), D26.1 (DOUT)
unnamed: D19.1 (DOUT), D27.4 (DIN)
unnamed: D20.4 (DIN), D28.1 (DOUT)
unnamed: D21.1 (DOUT), D29.4 (DIN)
unnamed: D22.4 (DIN), D30.1 (DOUT)
unnamed: D23.1 (DOUT), D31.4 (DIN)
unnamed: D24.4 (DIN), D32.1 (DOUT)
unnamed: D25.1 (DOUT), D33.4 (DIN)
unnamed: D26.4 (DIN), D34.1 (DOUT)
unnamed: D27.1 (DOUT), D35.4 (DIN)
unnamed: D28.4 (DIN), D36.1 (DOUT)
unnamed: D29.1 (DOUT), D37.4 (DIN)
unnamed: D30.4 (DIN), D38.1 (DOUT)
unnamed: D31.1 (DOUT), D39.4 (DIN)
unnamed: D32.4 (DIN), D40.1 (DOUT)
unnamed: D33.1 (DOUT), D41.4 (DIN)
unnamed: D34.4 (DIN), D42.1 (DOUT)
unnamed: D35.1 (DOUT), D43.4 (DIN)
unnamed: D36.4 (DIN), D44.1 (DOUT)
unnamed: D37.1 (DOUT), D45.4 (DIN)
unnamed: D38.4 (DIN), D46.1 (DOUT)
unnamed: D39.1 (DOUT), D47.4 (DIN)
unnamed: D40.4 (DIN), D48.1 (DOUT)
unnamed: D41.1 (DOUT), D49.4 (DIN)
unnamed: D42.4 (DIN), D50.1 (DOUT)
unnamed: D43.1 (DOUT), D51.4 (DIN)
unnamed: D44.4 (DIN), D52.1 (DOUT)
unnamed: D45.1 (DOUT), D53.4 (DIN)
unnamed: D46.4 (DIN), D54.1 (DOUT)
unnamed: D47.1 (DOUT), D55.4 (DIN)
unnamed: D48.4 (DIN), D56.1 (DOUT)
unnamed: D49.1 (DOUT), D57.4 (DIN)
unnamed: D50.4 (DIN), D58.1 (DOUT)
unnamed: D51.1 (DOUT), D59.4 (DIN)
unnamed: D52.4 (DIN), D60.1 (DOUT)
unnamed: D53.1 (DOUT), D61.4 (DIN)
unnamed: D54.4 (DIN), D62.1 (DOUT)
unnamed: D55.1 (DOUT), D63.4 (DIN)
unnamed: D56.4 (DIN), D64.1 (DOUT)
unnamed: D57.1 (DOUT), D58.4 (DIN)
unnamed: D59.1 (DOUT), D60.4 (DIN)
unnamed: D61.1 (DOUT), D62.4 (DIN)
unnamed: D63.1 (DOUT), D64.4 (DIN)
unnamed: F1.2, J1.1
unnamed: J1.3, R3.1
unnamed: J1.4, R4.1
unnamed: TP3.1, U1.8 (PC1/SDA)
unnamed: TP2.1, U1.9 (PC2/SCL)
unnamed: TP1.1, U1.10 (PC3/T1CH3)

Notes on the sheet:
Checklist --------- 3x Capacitive Touch - I/O Buzzer to Timer Ch USB CC lines pulldown USB Power - I/O Prog Conn - I/O Light Sense WS2812 Matrix
Pins
MCU
PWR IN
Connected to Timer2 CH3
WS2812B Matrix 8x8 1515 Size
Prog
Brightness++ -> Voltage++
Buzzer
LDR_DIV = R2/(R1+R2)*5V
LDR
C5349954

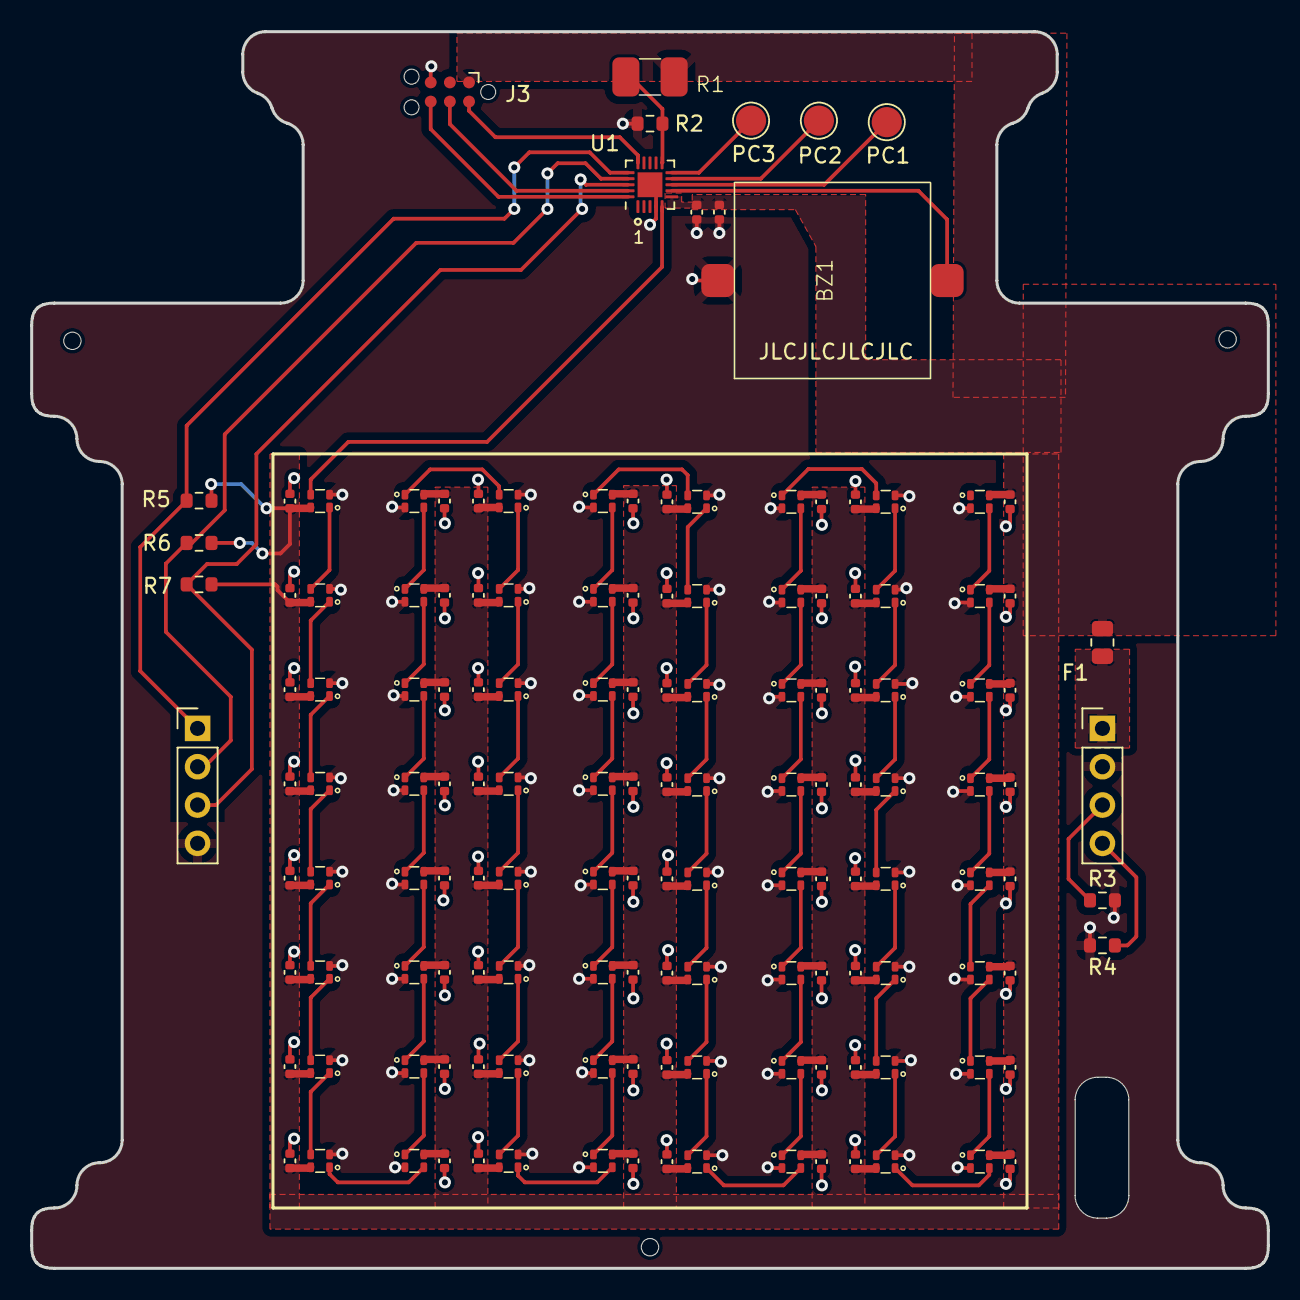
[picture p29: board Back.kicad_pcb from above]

Board: 2 copper layers, 82.0 x 82.0 mm, 149 parts (0 on the bottom side), 80 nets.

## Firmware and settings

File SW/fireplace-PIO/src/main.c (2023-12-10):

#include "ch32v003fun.h"
#include <stdio.h>

#define WS2812BSIMPLE_IMPLEMENTATION
//#define WS2812BSIMPLE_NO_IRQ_TWEAKING
#include "screen.h"

#include "frames.h"

#include "buzzer.h"

#include "photores.h"

#include "buttons.h"

#include "fire.h"

#include "wavetable.h"

#include "random.h"

typedef enum
{
	screenFire,
	screenAnimation,
	screenPresent,
	screenTreeFade
} ScreenState_t;

typedef enum
{
	Mute,
	Sound,
} SoundState_t;

int main()
{
	SystemInit();

	// Enable GPIOs
	RCC->APB2PCENR |= RCC_APB2Periph_GPIOD | RCC_APB2Periph_GPIOC;

	screen_init();

	// init TIM2 peripheral 
	t2pwm_init();

	// start systick IRQ to run timer
    systick_init();

	crackling_on();

	printf("initializing adc...");
	adc_init();
	printf("done.\n\r");

	printf("initializing capacitive buttons");
	buttons_init();
	printf("done.\n\r");

	// set seed for RNG
	random_seed(adc_get());

	Delay_Ms(1000);

	uint8_t animationNumber = 0;
	uint8_t animationFrameNumber = 0;
	ScreenState_t screen = screenFire;
	SoundState_t sound = Mute;
	uint32_t t = 0;
	uint8_t sine_idx = 0;

	while(1)
	{
		Delay_Ms(1);
		t++;

		// read buttons every x ms
		if(t%100 == 0){

			ScreenState_t oldscreen = screen;
			ScreenState_t newscreen = screen;

			buttonPress_t p = buttons_read_rising();

			switch (p)
			{
			case buttonNext:
				printf("Next");
				switch (oldscreen)
				{
				case screenAnimation:

					animationNumber++;
					animationFrameNumber = 0;
					change_song(animationNumber);
					if(animationNumber >= (sizeof(animations)/sizeof(animation_t))){
						newscreen = screenTreeFade;
					}
					break;
				case screenFire:
					newscreen = screenAnimation;
					break;
				case screenPresent:
				case screenTreeFade:
					newscreen = screenFire;	
					break;
				}
			break;
			case buttonPresent:
				printf("Present");
				switch (oldscreen)
				{
				case screenFire:
					crackling_off();
				case screenAnimation:
				case screenTreeFade:

					

					if(adc_get() > 400){
						change_song(5);
						for (int i = 0; i < 6; i++)
						{
							screen_write(no_present+i*64);
							Delay_Ms(100);
						}
						Delay_Ms(1000);
						for (int i = 0; i < 6; i++)
						{
							screen_write(no_present+(5-i)*64);
							Delay_Ms(100);
						}

						newscreen = screenFire;
						oldscreen = screenPresent;
					}else{
						change_song(3);
						for (int i = 0; i < 10; i++)
						{
							screen_write(present+i*64);
							Delay_Ms(100+500*(i%2));
						}

						for (int i = 0; i < 11; i++)
						{
							screen_write(present+(i+10)*64);
							Delay_Ms(300);
						}

						newscreen = screenPresent;
					}
					break;
				default:
					newscreen = screenFire;
					break;
				}
				break;
			case buttonSound:
				printf("Sound");
				if (sound == Mute) {
					music_on();
					sound = Sound;
				}
				else {
					music_off();
					sound = Mute;	
				}
				break;
			default:
				break;
			}

			// transition to new screen
			if(oldscreen != newscreen){
				switch (newscreen)
				{
				case screenFire:
					crackling_on();
					fire_reset();
					break;
				case screenAnimation:
					crackling_off();
					animationNumber = 0;
					animationFrameNumber = 0;
					change_song(0);
					break;
				case screenPresent:
					//crackling_off();
					animationFrameNumber = 0;
					break;
				case screenTreeFade:
					crackling_off();
					change_song(4); //feliz
					sine_idx = 0;
					break;
				default:
					break;
				}

				screen = newscreen;

			}
		}

		// Change fire frame
		if((t%32 == 0) && (screen == screenFire)){
			fire_draw();
		}

		// Change animation frame
		if((t%250 == 0) && (screen == screenAnimation)){
			screen_write(animations[animationNumber].data + animationFrameNumber*64);
			animationFrameNumber = (animationFrameNumber+1) % animations[animationNumber].numframes;
		}

		if((t%40 == 0) && (screen == screenTreeFade)) {

			for(int i = 0; i < 5; i++) {
				// wavetable is [0, 155], offset by 100 for [100,255] sine
				// phase offset by i*10 for offset fade order
				uint8_t brightness = sine_table[(sine_idx+i*10)%64]+100;
				uint32_t color = tree_colors[i];
				
				uint32_t blue = (color & 0x001F);  		// 5 bits blue  ............bbbbb -> 000bbbbb
				uint32_t green = (color & 0x07E0) >> 5; // 6 bits green .....ggg ggg..... -> 00gggggg
				uint32_t red = (color & 0xF800) >> 11;  // 5 bits red   rrrrr... ........ -> 000rrrrr

				// Scale by normalized brightness
				// brightness >> 8 = [0, 1]
				red = red*brightness >> 8;
				green = green*brightness >> 8;
				blue = blue*brightness >> 8;

				uint16_t faded = red << 11 | green << 5 | blue;

				tree[tree_idx[i]] = faded;
			}

			for (int i = 0; i < 10; i++) {
				uint8_t brightness = sine_table[(sine_idx+i*5)%64]+100;
				
				uint32_t color = (uint16_t)tree_colors[5];
				
				uint32_t blue = (color & 0x001F);  // 5 bits blue  ............bbbbb -> 000bbbbb
				uint32_t green = (color & 0x07E0) >> 5; // 6 bits green .....ggg ggg..... -> 00gggggg
				uint32_t red = (color & 0xF800) >> 11;   // 5 bits red   rrrrr... ........ -> 000rrrrr

				red = red*brightness >> 8;
				green = green*brightness >> 8;
				blue = blue*brightness >> 8;

				uint16_t faded = red << 11 | green << 5 | blue;
				tree[tree_idx[5+i]] = faded;
			}

			sine_idx++;
			sine_idx = sine_idx % 64; 
			screen_write(tree);
		}

	}
}

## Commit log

2023-10-28 Start on back PCB
    [Back.kicad_pcb, Back.kicad_sch]
2023-10-28 Add gitignore for kicad
2023-10-28 Add ch32 component
    [Back.kicad_sch]
2023-10-28 Added WS2812b
    [Back.kicad_pcb, Back.kicad_sch]
2023-10-28 Back Outline
    [Back.dxf, Back.kicad_pcb, Front.dxf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]
2023-10-28 Add outlines to PCBs
    [Back.kicad_pcb, Front.kicad_pcb, Front.kicad_sch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]
2023-10-28 Add USB to mid
    [Middle.dxf, Middle.kicad_pcb]
2023-10-28 USB-C contact added to mid
    [Middle.kicad_pcb, Middle.kicad_sch]
2023-10-28 update back schem
    [Back.kicad_sch]
2023-10-29 Updated back schematic
    [Back.kicad_sch]
2023-10-31 Back schematic finished
    [Back.kicad_sch]
2023-11-01 Front silks
    [Front.kicad_pcb]
2023-11-01 Middle silks
    [Middle.dxf, Middle.kicad_pcb]
2023-11-04 back layout done
    [Back.kicad_pcb, Back.kicad_sch, Middle.kicad_sch]
2023-11-04 Middle pcb done
    [Middle.kicad_pcb, Middle.kicad_sch]
2023-11-04 3D models
    [1.5mm led grid.stl, buzzer_C391038.step, female_pin_header.step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]
2023-11-04 Captivate sock
    [sock.dxf]
2023-11-04 Changed copper fill
    [Back.kicad_pcb]
2023-11-04 front pcb done
    [Front.kicad_pcb, Front.kicad_sch, female_pin_header.step]
2023-11-04 fixed step files
    [Back.step, Front.kicad_pcb, Front.step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]
2023-11-04 fixed usb-c cutout
    [Back.kicad_pcb, Back.step]
2023-11-04 adjusted usb-c cutout
    [Back.kicad_pcb, Back.step]
2023-11-05 Almost final adjustments
    [Back.kicad_pcb, Back.kicad_sch, Front.kicad_pcb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]
2023-11-05 Added dxf
    [back.dxf, front.dxf, middle.dxf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]
2023-11-05 Order num place and gerbers for front
    [Front-B_Cu.gbr, Front-B_Mask.gbr, Front-B_Paste.gbr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]
2023-11-05 Added small instruction text
    [Back.kicad_pcb]
2023-11-05 Adjusted icons
    [Middle.kicad_pcb]
2023-11-05 production files for back pcb
    [Back.kicad_pcb]
2023-11-05 gerbers for middle pcb
    [Middle-B_Cu.gbr, Middle-B_Mask.gbr, Middle-B_Paste.gbr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]
2023-11-26 IRQ disable, buzzer tone()
    [main.c]
2023-11-26 Added adc function
2023-11-26 Added adc read example and fixed printf
    [main.c]
2023-12-01 Buttons added
2023-12-01 Rework screen driver
2023-12-05 Updated grid and acrylic
    [Grid_v3.0.3mf, Grid_v3.0_diffuse_print.3mf, Grid_v3.0_print.3mf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]
2023-12-07 more frames
2023-12-09 Buttons working (?)
2023-12-09 Tune button thresholds
2023-12-09 New 3d prints
    [Grid_v3.1.3mf, Grid_v3.1_6.5mm_high.3mf, Grid_v3.1_print3mf.3mf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]
2023-12-09 Robust button measurement
2023-12-09 fixed snowman jazzhands frames
2023-12-10 Pogo_programming block
    [pogo_block_0.1.3mf, pogo_block_0.2.3mf, pogo_block_0.3.3mf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]
2023-12-11 Cleaned up schematic and generated pdfs
    [Back.kicad_sch, Front.kicad_sch, Middle.kicad_sch]
2023-12-11 Picture of mid PCB being soldered with jig
2024-01-21 Changed gitignore to include bom and placement files
2024-01-21 Added bom and placement files
    [bom.csv, designators.csv, positions.csv]
